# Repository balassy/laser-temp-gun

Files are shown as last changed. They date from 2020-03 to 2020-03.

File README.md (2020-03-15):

# Infrared Thermometer (aka. Laser Temp Gun)

A battery-powered infrared thermometer with a laser pointer built with an ESP8266 microcontroller and an MLX90614 sensor.

## Features

- Measures ambient and target object temperature with the MLX90614 infrared sensor. 
  - -40 … +125 °C for sensor temperature
  - -70 … +380 °C for object temperature
  - High accuracy of 0.5 °C over wide temperature range (0 … +50 °C for both Ta and To)
  - High (medical) accuracy calibration
  - Measurement resolution of 0.02 °C
- Shoots a laser beam to mark the target object.
- Powered by a 18650 battery (Model A) or a LiFePO4 3.2V AA battery (Model D).
- Measures battery level.
- Displays measured data on the Wemos OLED shield.
- Controlled by a Wemos D1 Mini microcontroller board.
- Allows charging the battery via a TP4056 charger (Model A).

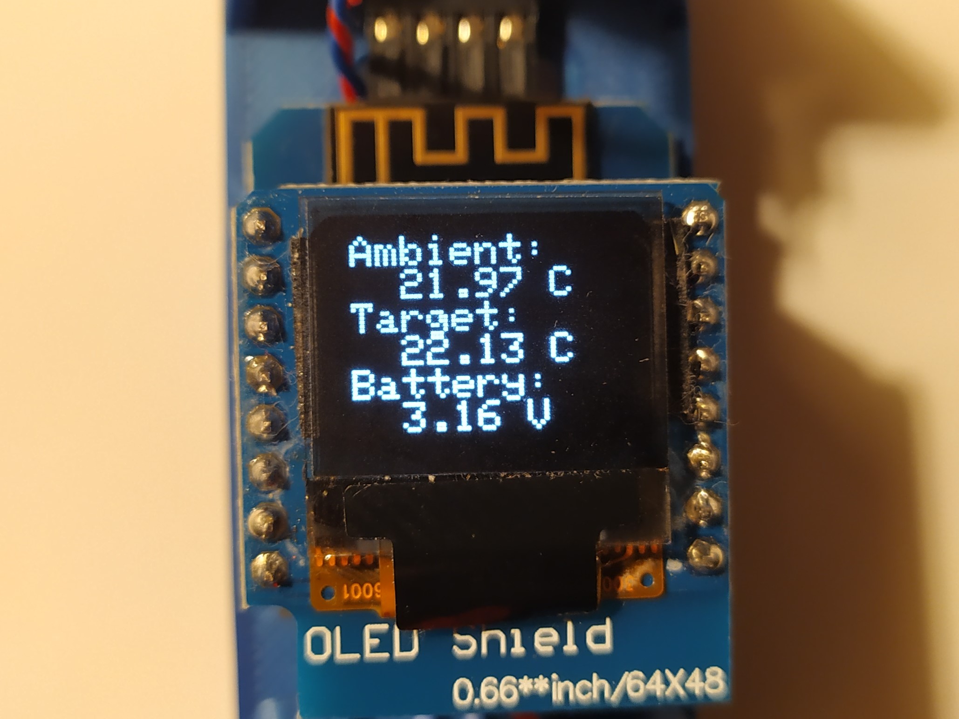
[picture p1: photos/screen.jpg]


The used microcontroller board has built-in WiFi capability, therefore it is possible to transmit the measured values over the wireless network for further processing (this feature is not implemented). 

## On this page

- [Features](#features)
- [On this page](#on-this-page)
- [Getting Started](#getting-started)
  - [Hardware](#hardware)
    - [Bill of Materials](#bill-of-materials)
    - [Wiring](#wiring)
  - [Software](#software)
    - [Prerequisites](#prerequisites)
    - [Setup](#setup)
  - [3D-Printed Case](#3d-printed-case)
- [About the author](#about-the-author)

(This Table of Contents was generated with [nGitHubTOC](https://imthenachoman.github.io/nGitHubTOC/), but [sompylasar's solution](https://github.com/isaacs/github/issues/215#issuecomment-456598835) is also very usable.)

## Getting Started

### Hardware

#### Bill of Materials

You need the following hardware components to build this project:
- Wemos D1 Mini controller board
- Wemos OLED shield
- MLX90614 infrared sensor
- 5V laser pointer
- 220K resistor (to measure the battery level)
- On-off switch
- Momentary push button
- For Model A:
  - 18650 battery
  - 18650 battery holder
  - TP4056 battery charger board
- For Model D:
  - LiFePO4 3.2V AA battery
  - Single AA battery holder
  - M3x6 screw to mount the battery holder

#### Wiring

Model A:

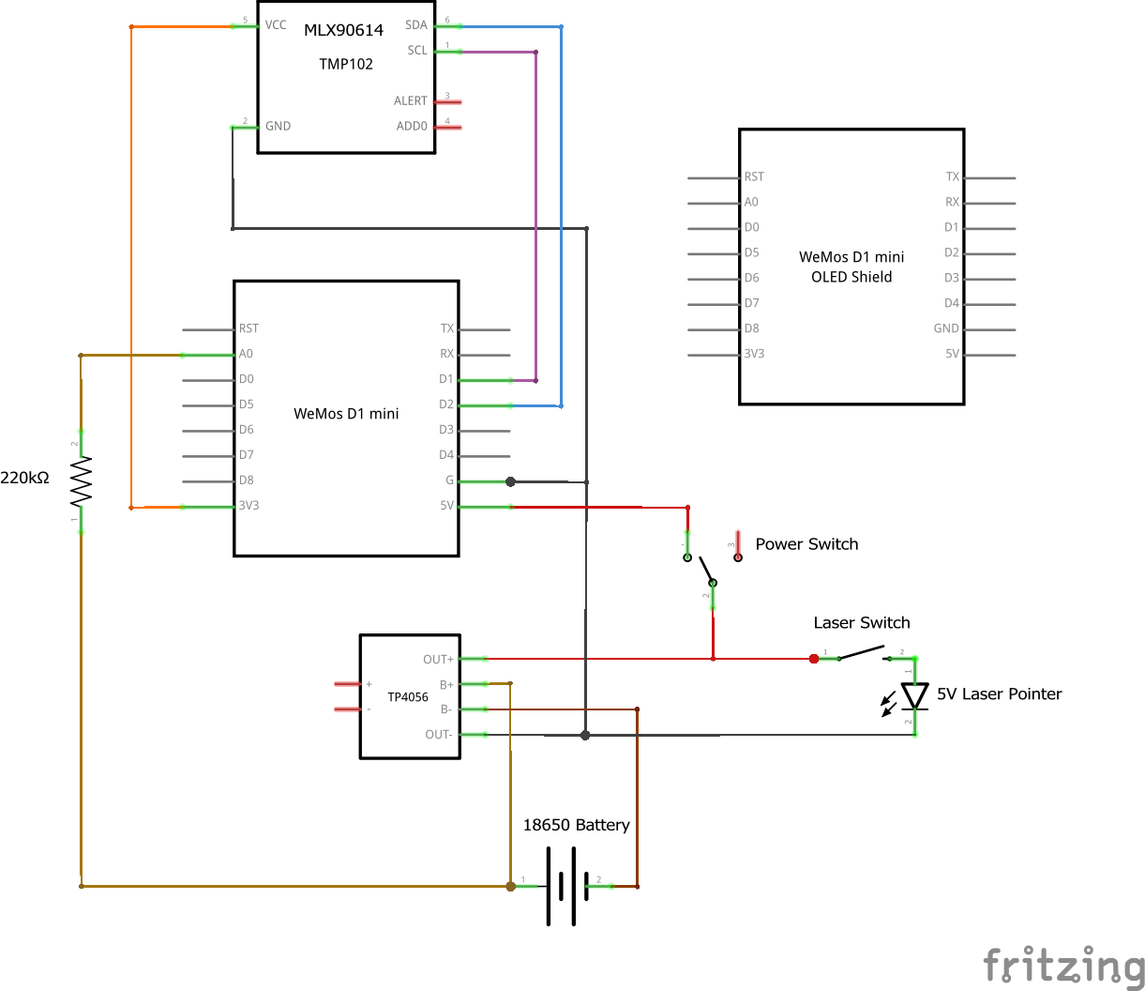
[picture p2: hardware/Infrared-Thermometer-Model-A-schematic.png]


Model D:

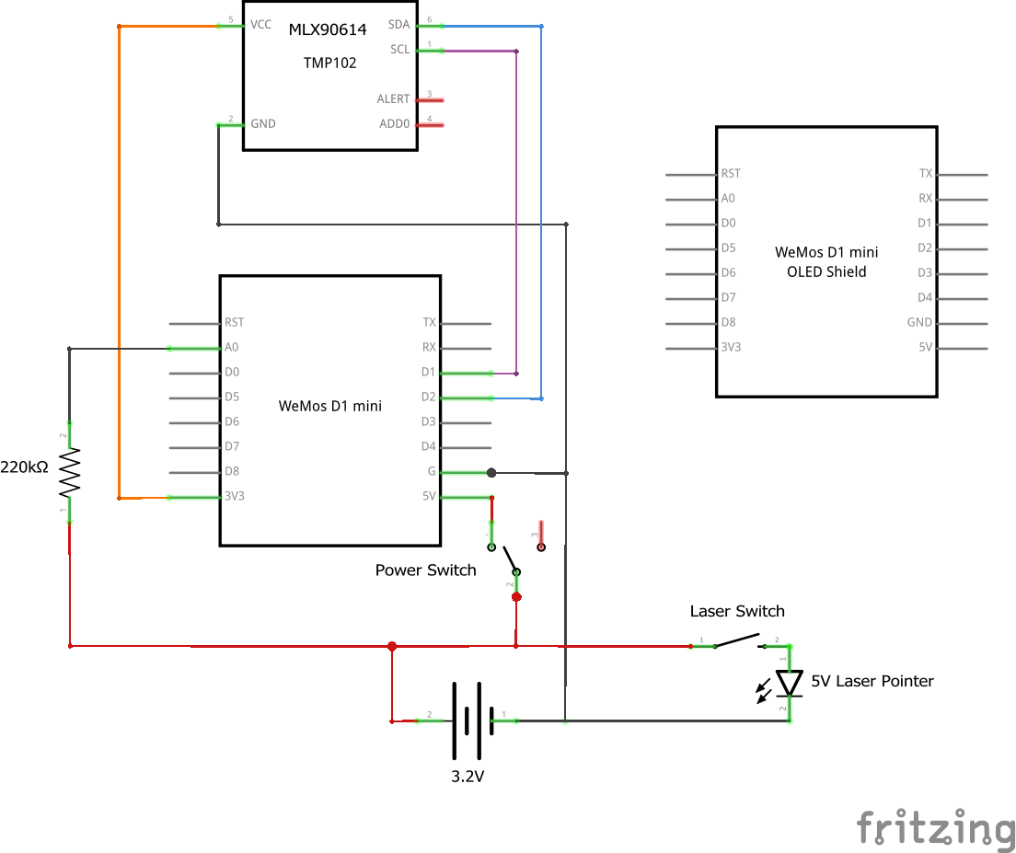
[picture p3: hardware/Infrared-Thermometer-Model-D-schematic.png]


You can find the Fritzing file in the `./hardware` folder.

### Software

#### Prerequisites

Install the following libraries in the Arduino IDE:
- Adafruit GFX Library by Adafruit.
- Adafruit SSD1306 Wemos Mini OLED by Adafruit + mcauser
- Adafruit MLX90614 by Adafruit.

#### Setup

Just compile and upload the [./software/InfraredThermometer/InfraredThermometer.ino](./software/InfraredThermometer/InfraredThermometer.ino) file from this repository and you are done! No additional configuration is necessary.

### 3D-Printed Case

I designed a 3D printable case only for Model D. It's more a part-holder bone than a full housing, but still it is functional and I find it cool that it reveals how the device is working.

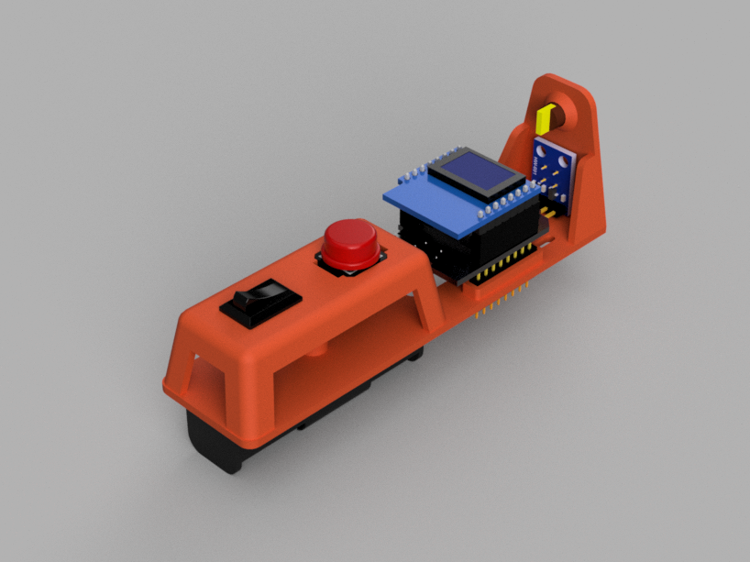
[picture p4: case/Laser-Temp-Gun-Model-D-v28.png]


You can find the 3D printable STL and all the source files in the `./case` folder. 

You can print with 0.2mm layer height without support. The holes for the buttons and the battery holder mounting screw is covered with a sacrificial layer to avoid supports, so you must remove that after printing.

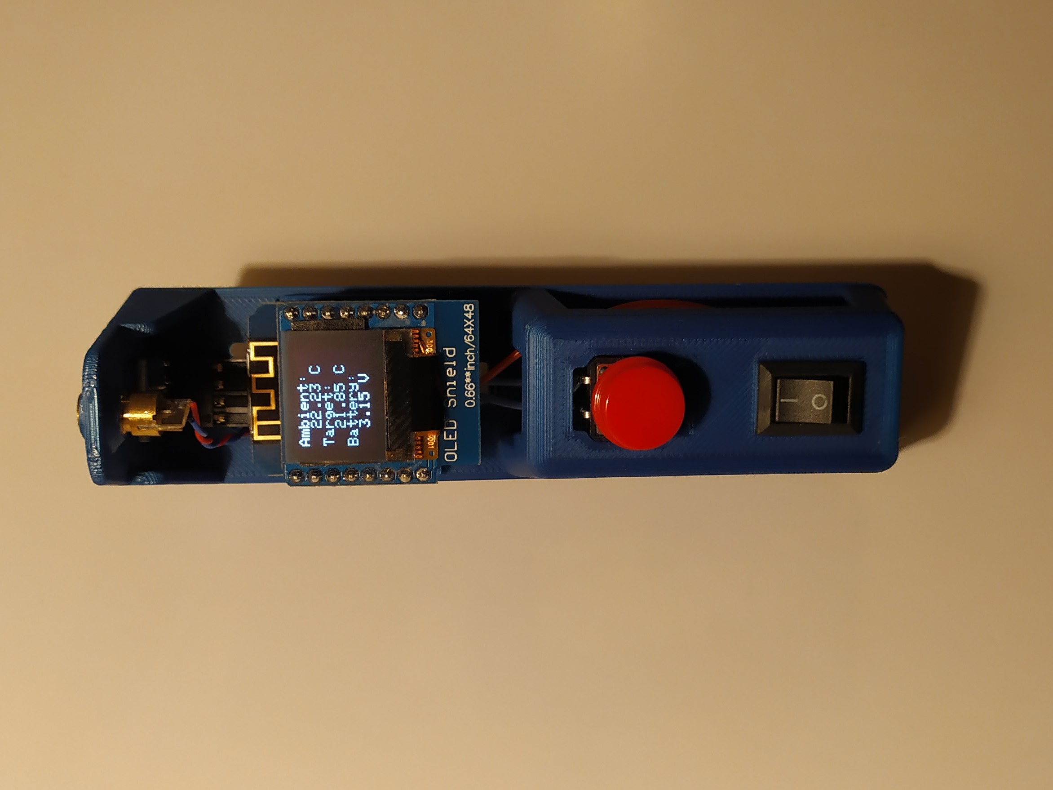
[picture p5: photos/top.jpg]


Shares on 3D printing community sites for comments and remixes:
- Thingiverse: https://www.thingiverse.com/thing:4222541
- PrusaPrinters: https://www.prusaprinters.org/prints/25513-infrared-thermometer-aka-laser-temp-gun

## About the author

This project is maintained by [György Balássy](https://linkedin.com/in/balassy).

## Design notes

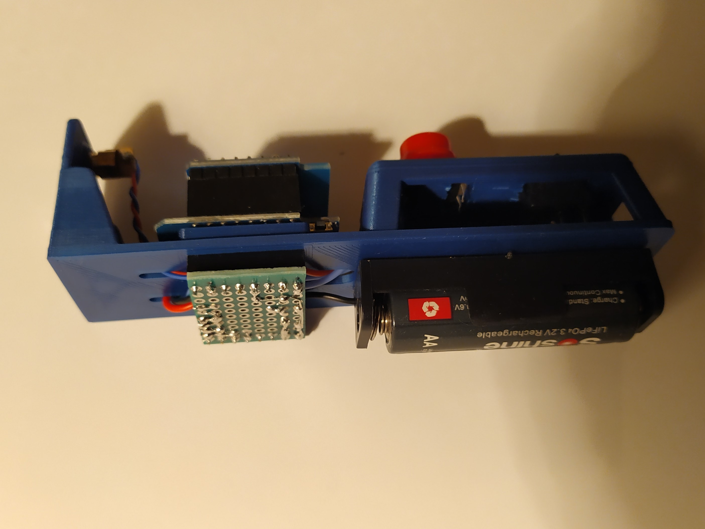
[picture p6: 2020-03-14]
photos/bottom.jpg

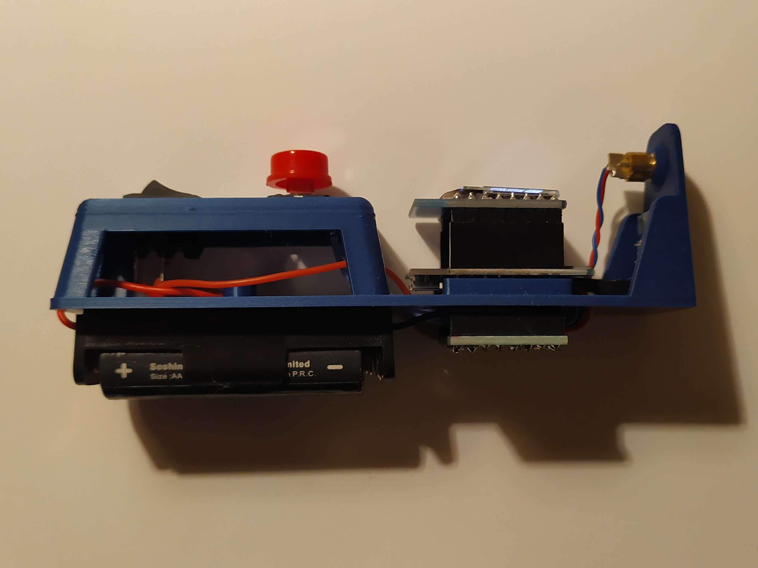
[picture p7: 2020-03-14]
photos/side.jpg

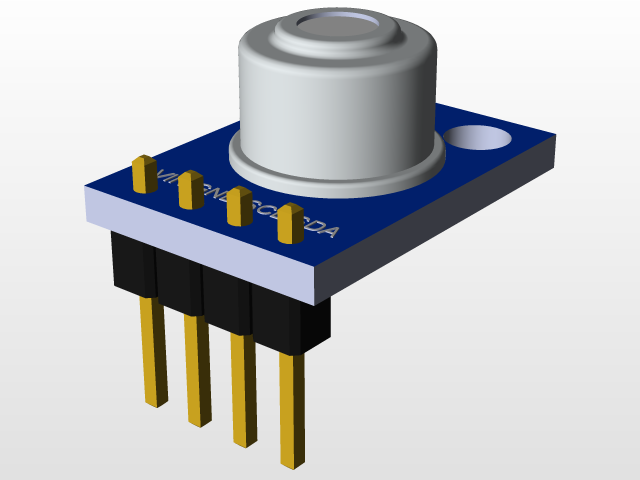
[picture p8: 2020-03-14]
case/MLX90614 Sensor/HW-691.png

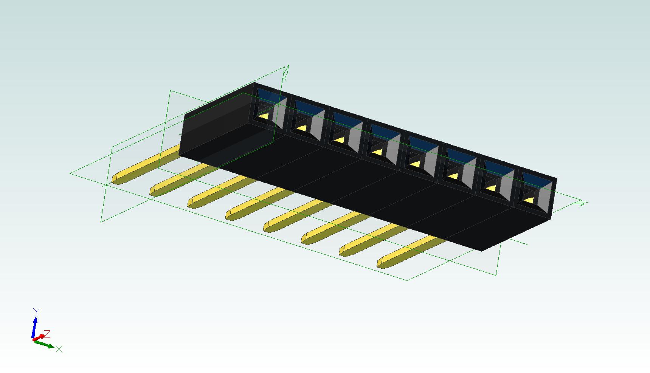
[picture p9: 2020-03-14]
case/Pin header stackable/SIL_Socket08.jpg

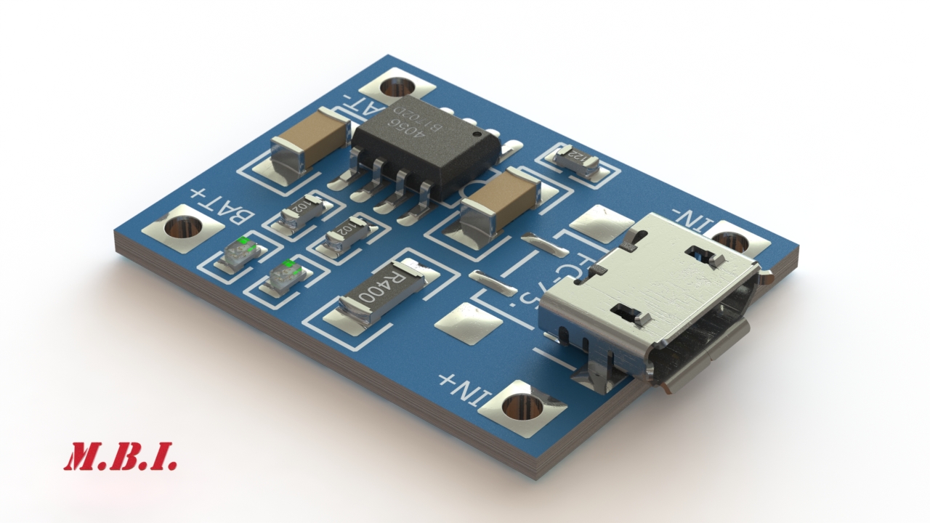
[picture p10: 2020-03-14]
case/TP4056 Charger/TP4056 Charger Module IMG_01.JPG

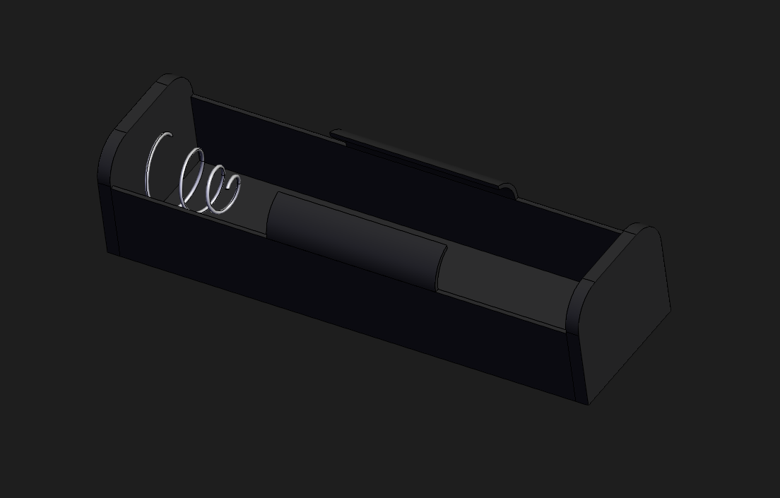
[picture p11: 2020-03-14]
case/AA Battery Holder/AA battery holder.png

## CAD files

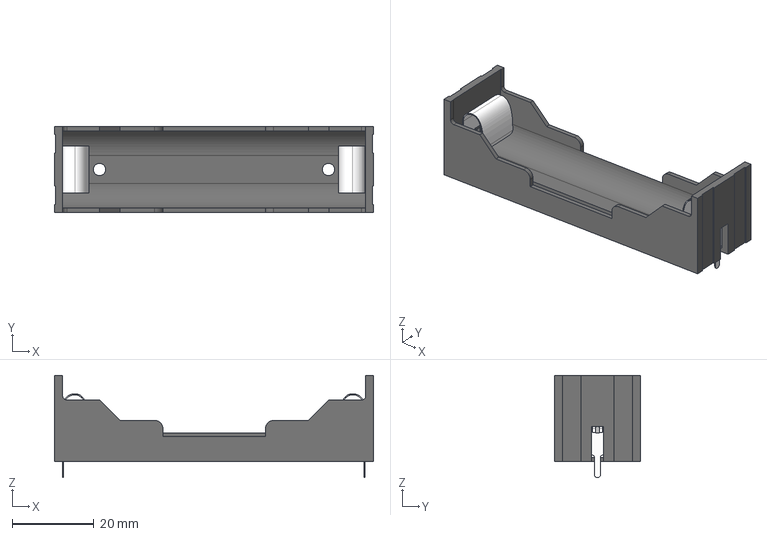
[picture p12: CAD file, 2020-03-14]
case/18650 Battery holder/BLOSSOM-BLM-18650-1PCS.step
78.0 x 21.0 x 25.0 mm
pin x 2

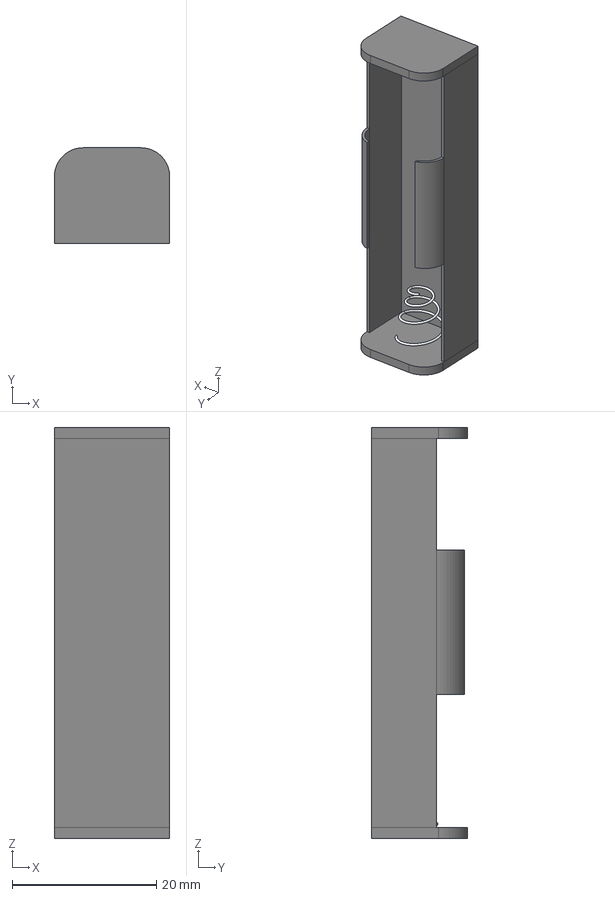
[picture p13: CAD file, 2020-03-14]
case/AA Battery Holder/AA battery holder.step
16.0 x 13.3 x 57.0 mm

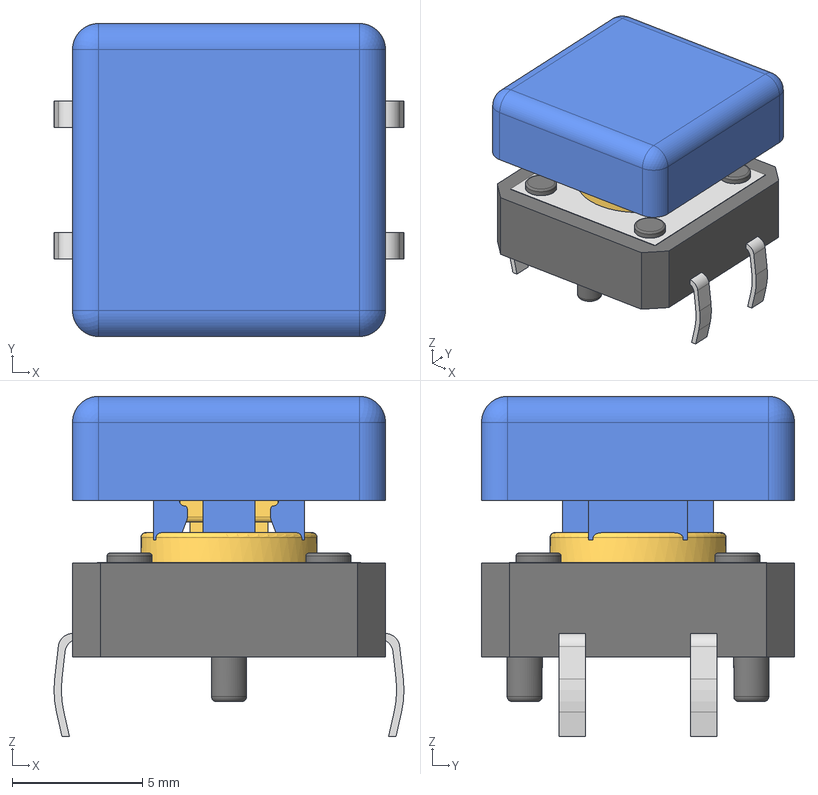
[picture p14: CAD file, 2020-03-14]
case/Button/12mmx12mm With Blue cap square.stp
13.4 x 12.0 x 13.0 mm

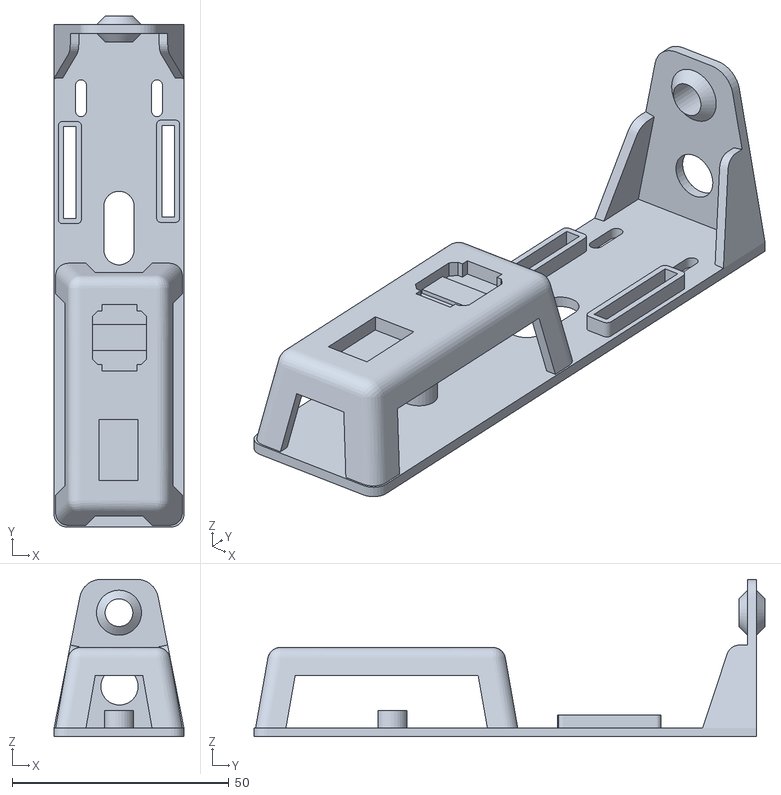
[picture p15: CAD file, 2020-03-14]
case/Laser Temp Gun Model D v28.stl
30.0 x 117.9 x 36.3

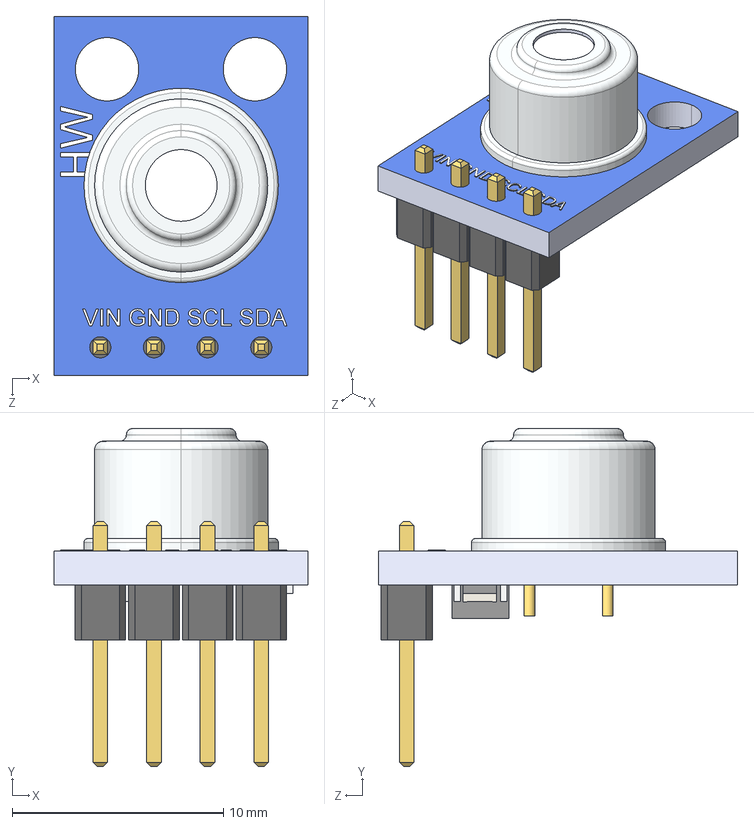
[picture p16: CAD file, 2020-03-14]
case/MLX90614 Sensor/HW-691.STEP
12.0 x 16.0 x 17.0 mm
IRTS_pcb
IRTS_pin x 4
IRTS_reistor x 2
IRTS_capacitor x 2
IRTS_Transistor
IRTS_IRSensor

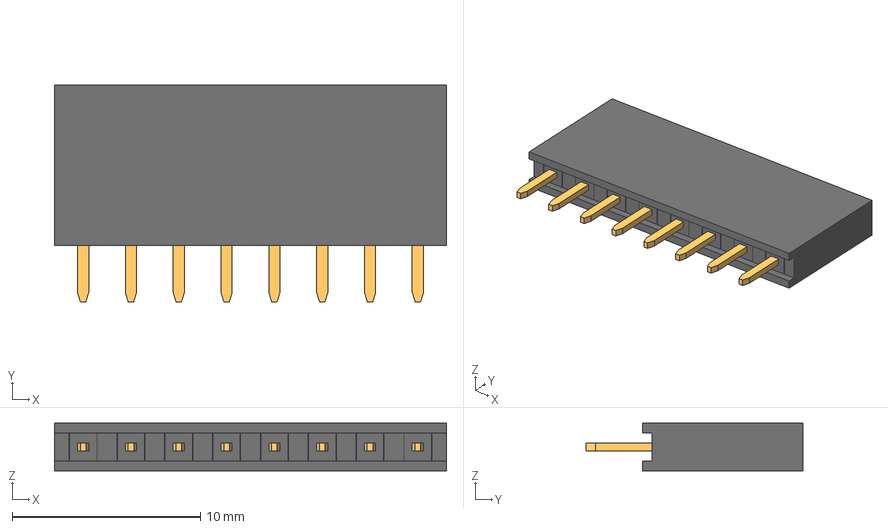
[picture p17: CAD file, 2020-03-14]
case/Pin header female/zl262-8s_p2-54_l20-8_w2-54_h8-5.stp
20.8 x 11.5 x 2.54 mm

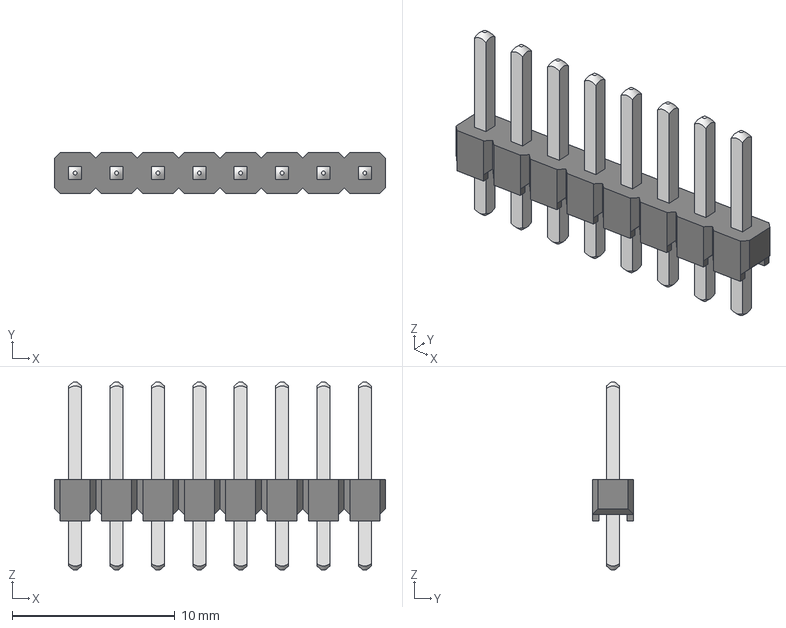
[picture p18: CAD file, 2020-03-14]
case/Pin header male/pin 8-2.54.stp
20.3 x 2.54 x 11.5 mm

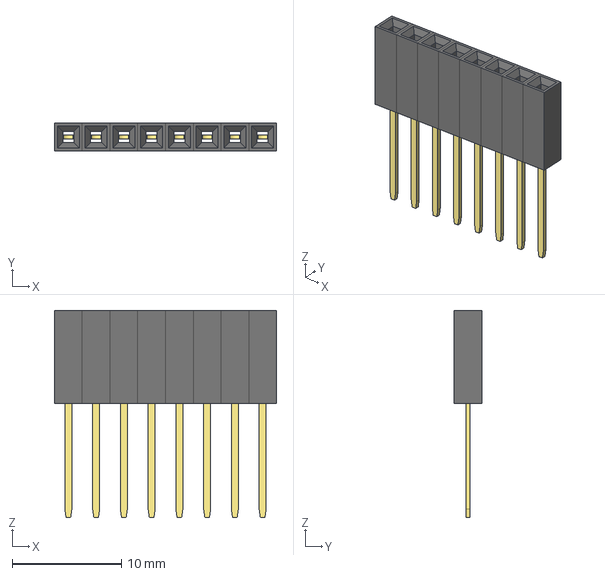
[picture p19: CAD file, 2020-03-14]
case/Pin header stackable/SIL_Socket08_.stp
20.3 x 2.54 x 19.0 mm

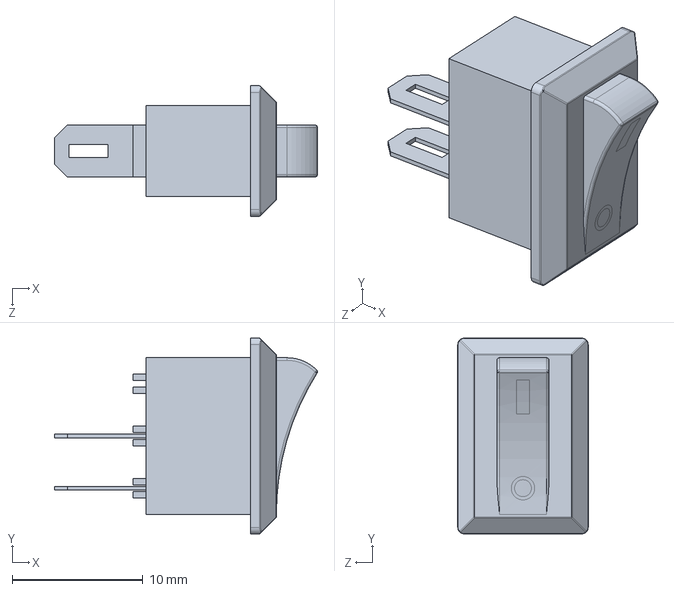
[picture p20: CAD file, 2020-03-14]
case/Switch/10x15mm SPST 2pin on_off G130 Boat Rocker Switch 3A-250V.STEP
20.2 x 15.0 x 10.0 mm

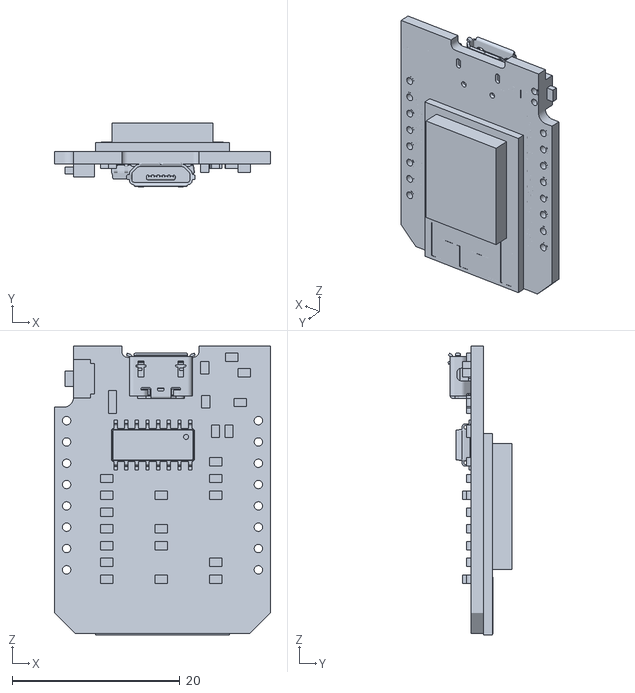
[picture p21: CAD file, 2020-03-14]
case/Wemos D1 Mini/WEMOS-D1-mini_stl.STL
25.8 x 7.60 x 34.4

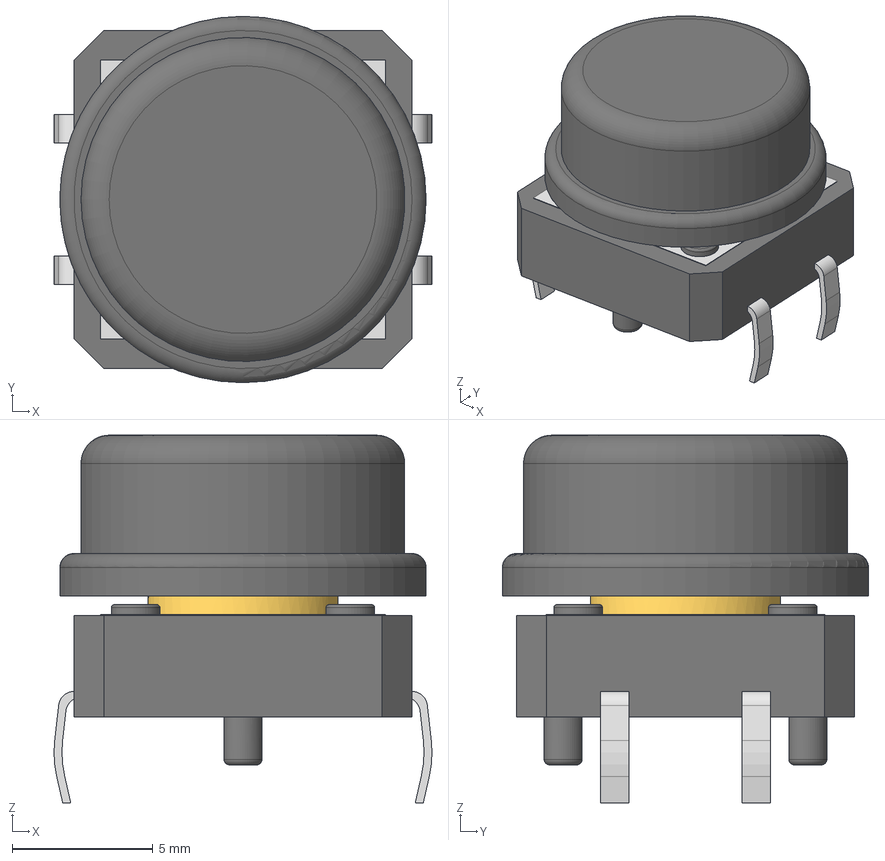
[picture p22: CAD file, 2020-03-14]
case/Button/12mmx12mm With Black cap round.stp
13.4 x 13.0 x 13.0 mm

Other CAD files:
case/Button/12mmx12mm With Yellow cap round.stp
case/Button/12mmx12mm With Blue cap round.stp
case/Button/12mmx12mm With White cap round.stp
case/Button/12mmx12mm With Yellow cap square.stp
case/Button/12mmx12mm With White cap square.stp
case/Button/12mmx12mm With Red cap round.stp
case/Button/12mmx12mm With Green cap round.stp
case/18650 Battery holder/BLOSSOM-BLM-18650-1PCS v3.f3d
case/Button/12mmx12mm With Black cap square.stp
case/Button/12mmx12mm With Green cap square.stp
case/Button/12mmx12mm With Red cap square.stp
case/Button/12mmx12mm Without cap.stp
case/Laser Diode/Laser Diode 5V 6mm.ipt
case/Laser Temp Gun Model D v28.f3z
case/Pin header female/zl262-8s_p2-54_l20-8_w2-54_h8-5.igs
case/Pin header stackable/SIL_Socket08_.stl

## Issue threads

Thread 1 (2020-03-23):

Mistake in wiring diagram

Karlosek, 2020-03-23:
There is a mistake in diagram version D. Wrong polarity of battery.

balassy, 2020-03-24:
You're right, I fixed it now in commit 86c9a865e17aad74b8ada2b31e17f73adba216dc. Thanks for pointing that out!

Closed 2020-03-24.

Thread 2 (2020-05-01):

Is there any way to improve the accuracy of the mlx90614?

jhysum, 2020-05-01:
Hi,

This isn't an issue for the temp gun repo but I was wondering if there is any way for you to improve the accuracy beyond .5C?

If you have any advice for this, I'll love to hear about it.

balassy, 2020-05-03:
The 0.5 C accuracy is the official nominal value of the sensor, and I don't know any way to improve it. I ordered my sensor from AliExpress and this particular cheap device is way more off than 0.5 C :(

Closed 2020-05-03.

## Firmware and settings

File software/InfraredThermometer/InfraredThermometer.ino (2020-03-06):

#include <SPI.h>
#include <Wire.h>

// Third-party libraries:
#include <Adafruit_GFX.h>       // Adafruit GFX Library by Adafruit.
#include <Adafruit_SSD1306.h>   // Adafruit SSD1306 Wemos Mini OLED by Adafruit + mcauser
#include <Adafruit_MLX90614.h>  // Adafruit MLX90614 by Adafruit.

// SCL GPIO5
// SDA GPIO4
#define OLED_RESET 0  // GPIO0
Adafruit_SSD1306 display(OLED_RESET);

#if (SSD1306_LCDHEIGHT != 48)
#error("Height incorrect, please fix Adafruit_SSD1306.h!");
#endif

Adafruit_MLX90614 mlx = Adafruit_MLX90614();

void setup() {
  initSerial();
  initDisplay();
  initSensor();

  displayBootMessage();
  delay(1500);
}

void loop() {
  double ambientTempC = mlx.readAmbientTempC();
  double targetTempC = mlx.readObjectTempC();
  float voltage = readBatteryVoltage();
  
  Serial.print("Ambient = "); 
  Serial.print(ambientTempC); 
  Serial.print("°C\tTarget = "); 
  Serial.print(targetTempC); 
  Serial.println("°C");

  displayMeasuredData(ambientTempC, targetTempC, voltage);

  delay(1000);
}


void initSerial() {
  Serial.begin(74880); // 74880 is the speed used to print boot messages.
  Serial.println();
  Serial.println(F("Initializing serial connection DONE."));
}

void initDisplay() {
  Serial.print(F("Initializing the display..."));
  // By default, we'll generate the high voltage from the 3.3v line internally.
  display.begin(SSD1306_SWITCHCAPVCC, 0x3C);  // initialize with the I2C addr 0x3C (for the 64x48).
  Serial.println(F("DONE."));
}

void initSensor() {
  Serial.print(F("Initializing the sensor..."));
  mlx.begin();
  Serial.println(F("DONE."));
}


void displayBootMessage() {
  // The display buffer is intialized with an Adafruit logo
  // internally, so first let's delete that.
  display.clearDisplay();
  
  display.setTextSize(1);  // Size 1 means each character is 6 width and 8 high.
  display.setTextColor(WHITE);
  display.setCursor(10,25);

  display.println("Welcome!");
  display.display();  
}

void displayMeasuredData(double ambientTempC, double targetTempC, float voltage) {
  display.clearDisplay();

  display.setTextSize(1);
  display.setTextColor(WHITE);
  display.setCursor(0,0);

  display.println("Ambient:");
  display.print("  ");
  display.print(ambientTempC);
  display.println(" C");
  display.println("Target:");  
  display.print("  ");
  display.print(targetTempC);
  display.println(" C");
  display.println("Battery:");  
  display.print("  ");
  display.print(voltage);
  display.println(" V");

  display.display();
  delay(1);  
}

float readBatteryVoltage() {
  // Voltage divider R1 = 220k+100k+220k =540k and R2=100k
  float calib_factor = 5.28; // change this value to calibrate the battery voltage
  unsigned long raw = analogRead(A0);
  float volt = raw * calib_factor/1024; 
  return volt;
}

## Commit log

2020-03-06 doc: added wiring
    [Infrared Thermometer.fzz]
2020-03-06 fix: wiring link in README
    [Infrared-Thermometer-.fzz]
2020-03-14 doc: added Model D wiring
    [Infrared-Thermometer-Model-A.fzz, Infrared-Thermometer-Model-D.fzz]
2020-03-14 feat: 3D printable case
    [10x15mm SPST 2pin on_off G130 Boat Rocker Switch 3A-250V.STEP, 12mmx12mm With Black cap round.stp, 12mmx12mm With Black cap square.stp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]
2020-03-14 fix: deleted outdated model files
    [Laser Temp Gun Model D v23.stl]
2020-03-24 fix: corrected the battery polarity on the Model D schematic diagram
    [Infrared-Thermometer-Model-D.fzz]
